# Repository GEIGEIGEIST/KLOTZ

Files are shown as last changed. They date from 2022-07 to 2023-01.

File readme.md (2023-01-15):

<picture>
  <source media="(prefers-color-scheme: dark)" srcset="/docs/images/KLOTZ_font_dark.svg">
  <source media="(prefers-color-scheme: light)" srcset="/docs/images/KLOTZ_font_bright.svg">
  KLOTZ logo font
</picture>

# KLOTZ SPLIT KEYBOARD

KLOTZ is a 34 key column-staggered choc split keyboard running [ZMK](https://zmk.dev/). It supports a low profile encoder, three status LEDs on every side and the SplitKB tenting puck.

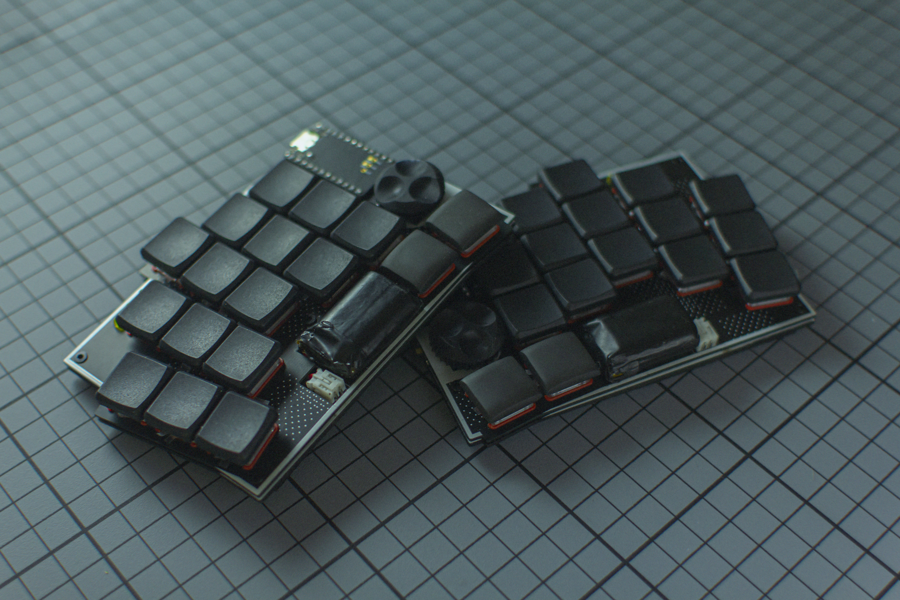
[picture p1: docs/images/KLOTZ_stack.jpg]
KLOTZ stacked


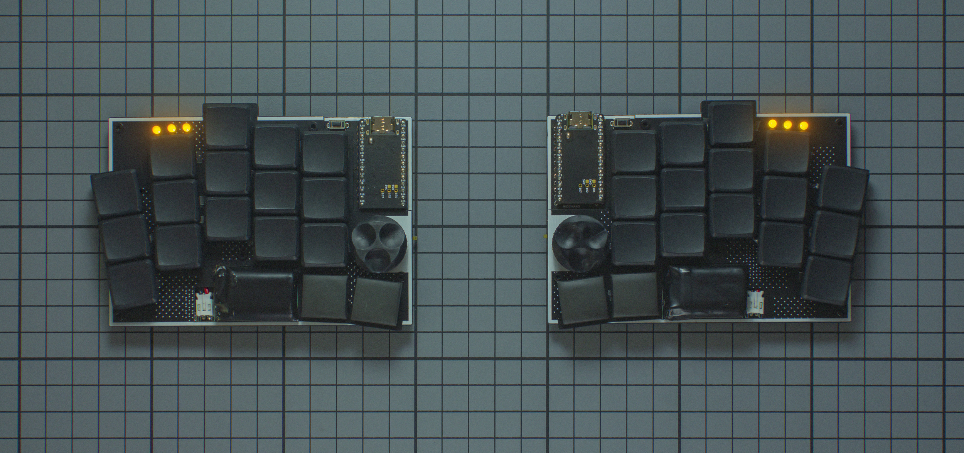
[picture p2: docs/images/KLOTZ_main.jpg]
KLOTZ


## LAYOUT

KLOTZ layout

## PCB

[Here](/PCB/) you can find the KiCad files and Gerbers for the KLOTZ.

## SWITCHPLATE

And [here](/switchplate/) is the switchplate, which you should use, if you plan to use hotswap sockets.

## KNOB

You can use pretty much any knob, which works with EC12 encoder, but [here](/knob/) you can find one, I designed for the KLOTZ.

## BUILD GUIDE

The build guide for the KLOTZ can be found [here](/docs/buildguide.md).

## FIRMWARE

[ZMK config](https://github.com/GEIGEIGEIST/zmk-config-klotz) for the KLOTZ.

## TRAVELCASE

Since a lot of people use the Amazon basics harddrive case (ZH1510147) for the KLOTZ I thought I should put an (affiliate) link in here. 

[US Amazon link](https://www.amazon.com/gp/product/B00F5CKWBA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)

[German Amazon link](https://www.amazon.de/gp/product/B00F5CKWBA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)

 If you build a KLOTZ I would be pretty happy to see some pictures. And if you want to leave me a tip you can do this [here](https://ko-fi.com/geigeigeist) (but please don't feel pressured)

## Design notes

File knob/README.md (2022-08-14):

# KLOTZ KNOB

This is the EC12 encoder knob for the KLOTZ. You should be able to print it in FDM, but for best results consider to print it in SLA.\
I can recommend to get it printed at [JLCPCB](https://jlcpcb.com/)

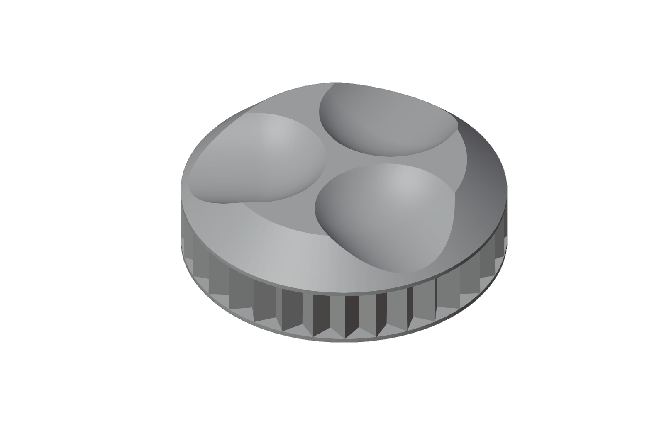
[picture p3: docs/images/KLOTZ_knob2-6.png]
KLOTZ knob


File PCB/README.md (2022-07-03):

# KLOTZ PCB

## MANUFACTURING
If you want to get the PCB made you need to upload the **KLOTZ_0-2_gerbers.zip** file to the website of the manufacture ([JLCPCB](https://jlcpcb.com/) for example).

- upload the ZIP
- sometimes the Gerber preview from JLCPCB can't display the PCB, even when the files are fine. In this case use this dimensions: 120.5 mm* 85.5 mm
- PCB Thickness 1.6mm
- 2 layers
- PCB Qty as much as you like. But be aware, that you need 2 PCBs for one keyboard
- PCB Color Black
- No impedance control
- Surface Finish HASL(with lead) if you want the easiest soldering experience or LeadFree HASL.
- Remove Order Number Yes

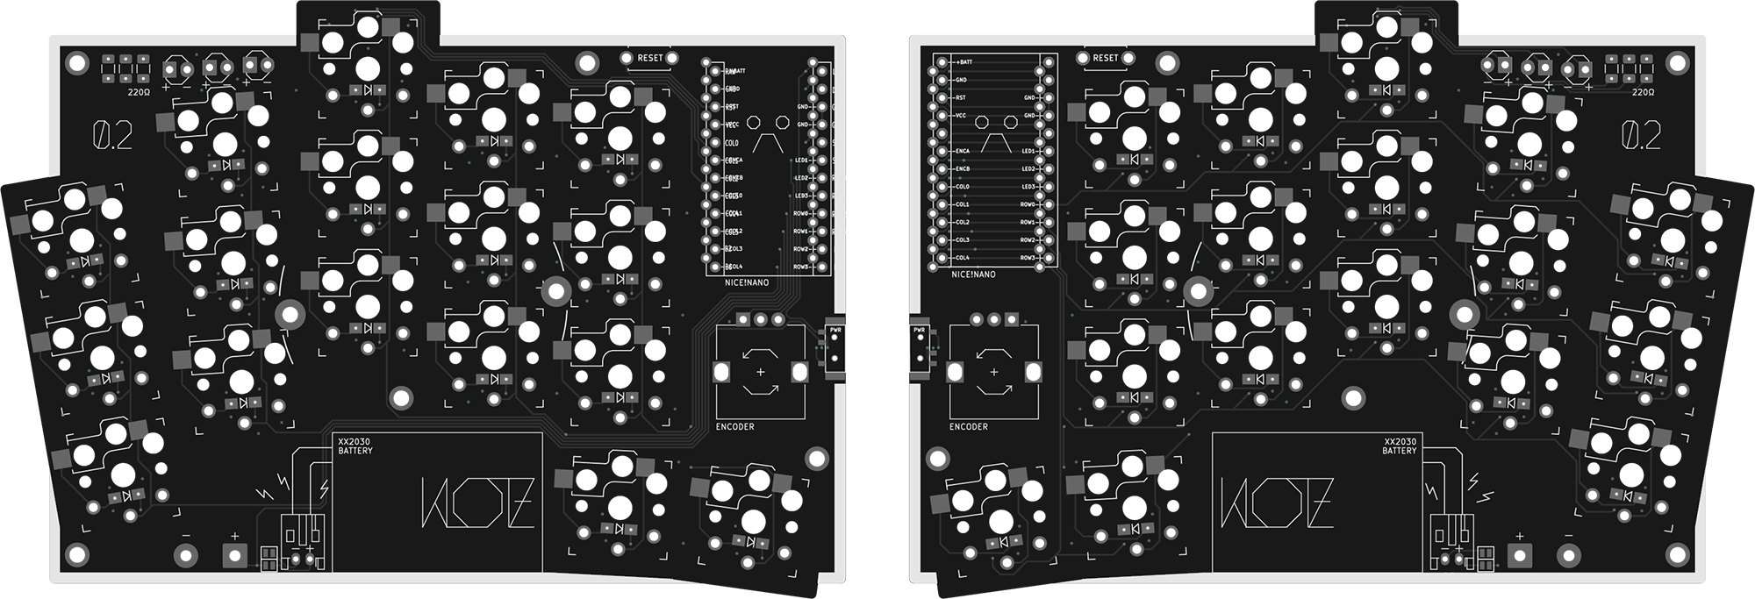
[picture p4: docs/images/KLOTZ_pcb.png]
KLOTZ PCB


## CHECK TRACES OR PINOUT

If you only want to check the traces or see what is connected to which pin you can take a look at these graphics.

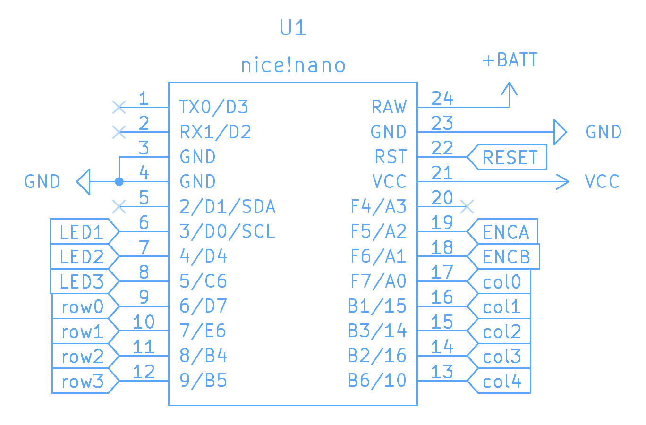
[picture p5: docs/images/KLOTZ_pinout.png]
KLOTZ pinout

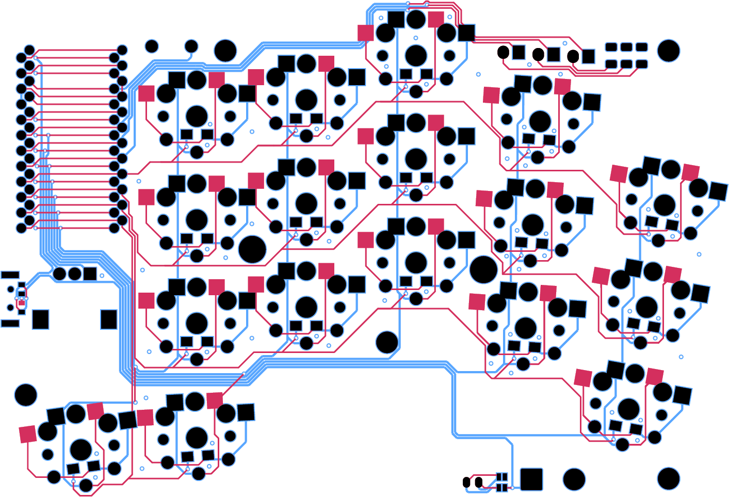
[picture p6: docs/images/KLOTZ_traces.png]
KLOTZ traces


## TAKE A DEEPER LOOK OR MODIFY 

You can download the project if you need to take a deeper look or modify something. You need the Open Source software [KiCad](https://www.kicad.org/) to open it.

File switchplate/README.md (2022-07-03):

# KLOTZ SWITCHPLATE

If you plan to use the KLOTZ with hotswap sockets you should use a switchplate. If you plan on solder in the switches it looks nicer.

## MANUFACTURING
If you want to get the switchplate made you need to upload the **KLOTZ_0-2_plate_gerbers.zip** file to the website of the manufacture ([JLCPCB](https://jlcpcb.com/) for example).

- upload the ZIP
- sometimes the Gerber preview from JLCPCB can't display the PCB, even when the files are fine. In this case use this dimensions: 120.5 mm* 85.5 mm
- PCB Thickness 1.2mm (this is crucial to make Choc switches snap in)
- 2 layers
- PCB Qty as much as you like. But be aware, that you need 2 plates for one keyboard
- PCB Color Black
- No impedance control
- Surface Finish HASL(with lead) or LeadFree HASL
- Remove Order Number Yes
- Flying Probe Test Not Test

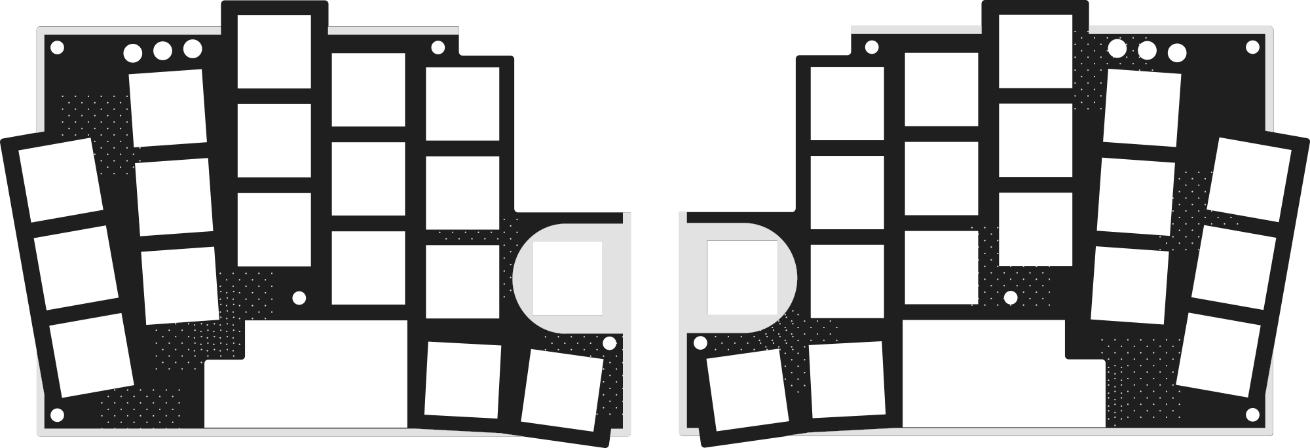
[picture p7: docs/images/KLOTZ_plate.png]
KLOTZ switchplate


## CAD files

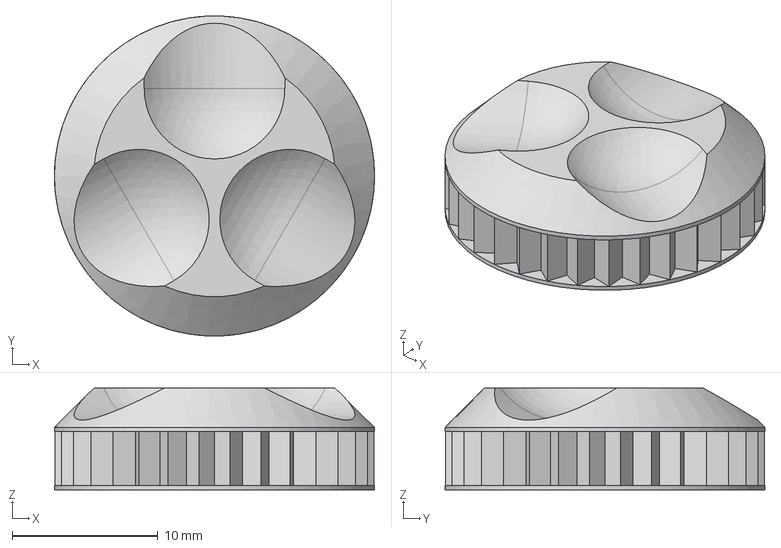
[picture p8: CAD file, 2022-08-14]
knob/GEIST_EC12knob_v02_06.step
22.0 x 22.0 x 7.00 mm

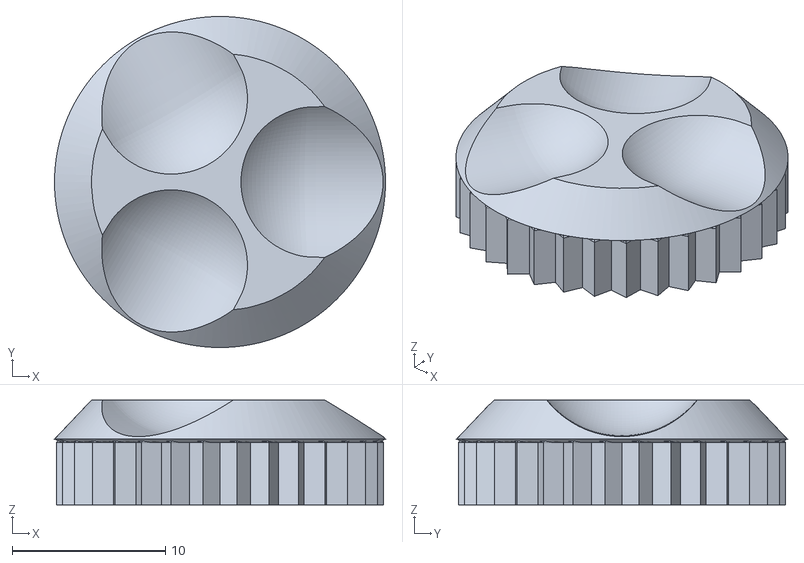
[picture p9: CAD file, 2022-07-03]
knob/KLOTZ_EC12-knob_v02_04.stl
21.6 x 21.6 x 6.86

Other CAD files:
knob/GEIST_EC12knob_v02_06.stl

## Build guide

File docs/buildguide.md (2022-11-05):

# KLOTZ BUILDGUIDE (WIP)

## PART LIST

### REQUIRED PARTS

| Part name | Count | Remarks | 
| :--- | :---: | :--- |
| KLOTZ PCB | 02 | You can find the files for it [here](/PCB/) |
| KLOTZ switchplate | 02 | Which you can find [here](/switchplate/) |
| nice!nano | 02 | Alternatively, you can use another controller with similar pinout and bluetooth capabilities like the Puchi-BLE |
| Choc key switch | 34 | Kailh Choc low profile keyswitches |
| diodes 1N4148W | 34 | These are surface mount diodes in SOD123 package |
| 1u Choc keycaps | 34 | You can use the black or white keycaps from Kailh, but I recommend MBK keycaps |
| reset button | 02 | Through-hole, 2 pin tactile buttons |
| power switch | 02 | MSK12C02 |
| EC12 encoder | 02 | Technically you could also use EC11 encoder, but flat EC12 like the EC12E2440301 will work best |
| encoder knob | 02 | Nearly every encoder knob, which works with the EC12 should work. But if you have acces to a printer you can use [this one](/knob/) |
| USB cable | 01 | For connecting the keyboard with your PC |
| Lipo battery | 02 | You can use a variety of Lipo batteries, but the cutout in the switchplate is meant to be used with a battery which name ends with 2030, like the 902030.

### OPTIONAL PARTS

| Part name | Count | Remarks | 
| :--- | :---: | :--- |
| MCU sockets | 04 | For socketing your MCU. Highly recommended |
| MCU pins | 48 | In combinatin with the MCU sockets |
| JST Jack | 02 | JST PH |
| switch socket | 34 | Switch sockets for Kailh choc switches |
| LEDs | 06 | 3mm through hole LEDs |
| resistors | 06 | R1206 220ohm SMD resistors for the LEDs |
| screws  				 | 10 | 6mm M2 screws |
| bolts | 10 | M2 bolts |
| o-rings | 10 | as optional standoffs. OD4*1.5-150NB |
| [tenting puck](https://splitkb.com/products/tenting-puck)| 02 | SplitKB Tenting Puck |

## INTRODUCTION

Here is an overview of where and on which side each component needs to be soldered (click on the image to see a larger version).

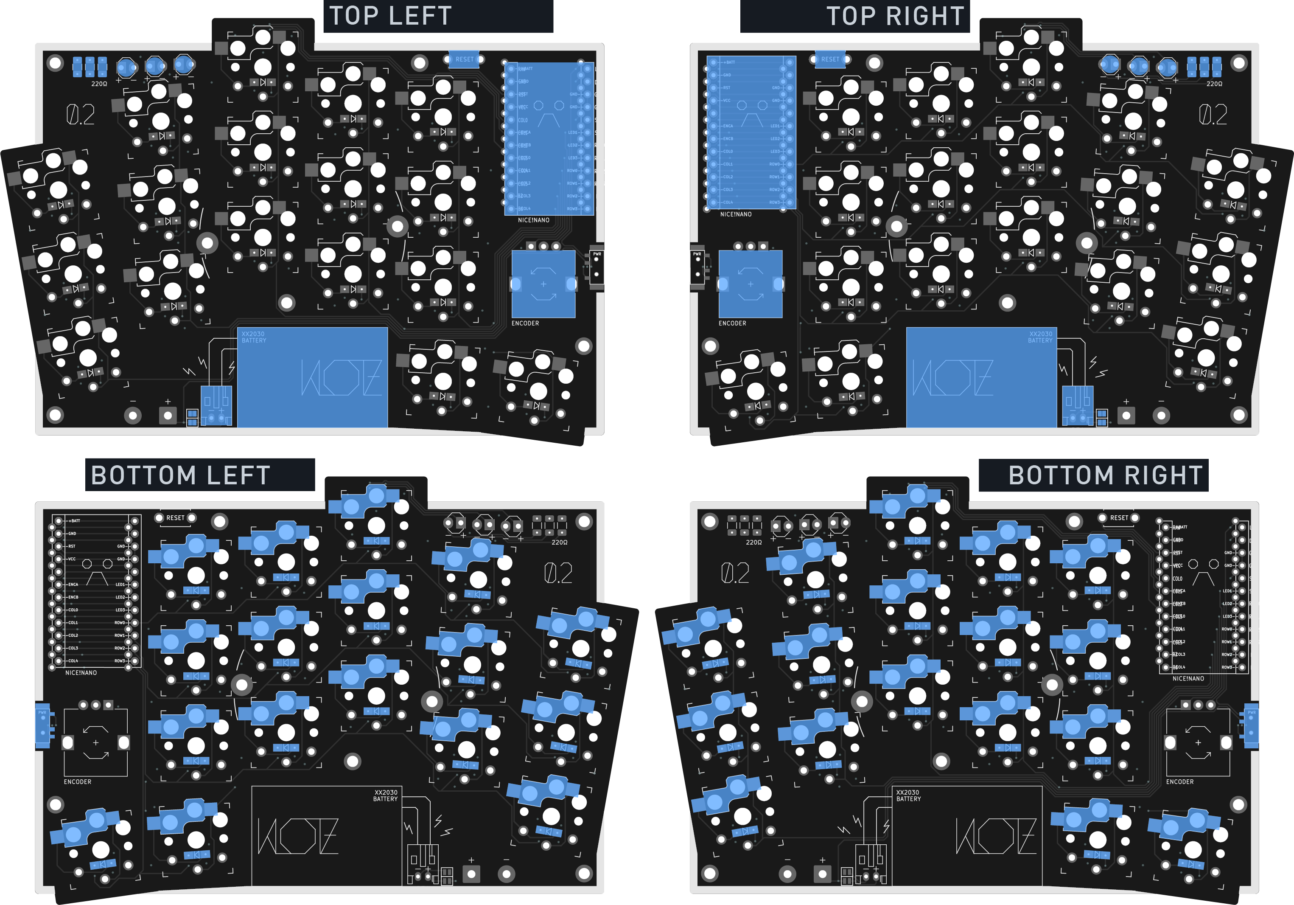
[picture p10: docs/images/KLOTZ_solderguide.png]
KLOTZ solder guide


To see what component needs to sit where you can take a look at the [interactive HTML BOM](https://htmlpreview.github.io/?https://github.com/GEIGEIGEIST/KLOTZ/blob/main/docs/klotz_rev0-2_ibom.html).

> **Warning**
> This interactive HTML BOM does show where each component is located, but please still refer to the solder guide above to see if a component needs to go on the top or bottom of the PCB.

***

## DIODES

The diodes needs to be soldered on the bottomm of the PCB. Pay attention to their orientation:  They have a small line on one side, which should be on the side the arrow on the PCB is facing to.

<p align="center">
<picture>
  <source media="(prefers-color-scheme: dark)" srcset="/docs/images/buildguide/diodes_dark.svg">
  <source media="(prefers-color-scheme: light)" srcset="/docs/images/buildguide/diodes_bright.svg">
  diode orientation
</picture>
</p>

Apply a small amount of solder on one pad.\
Then use tweezers to place the diode on the pads and reheat the solder to secure the diode.
Now you can solder the second pad.

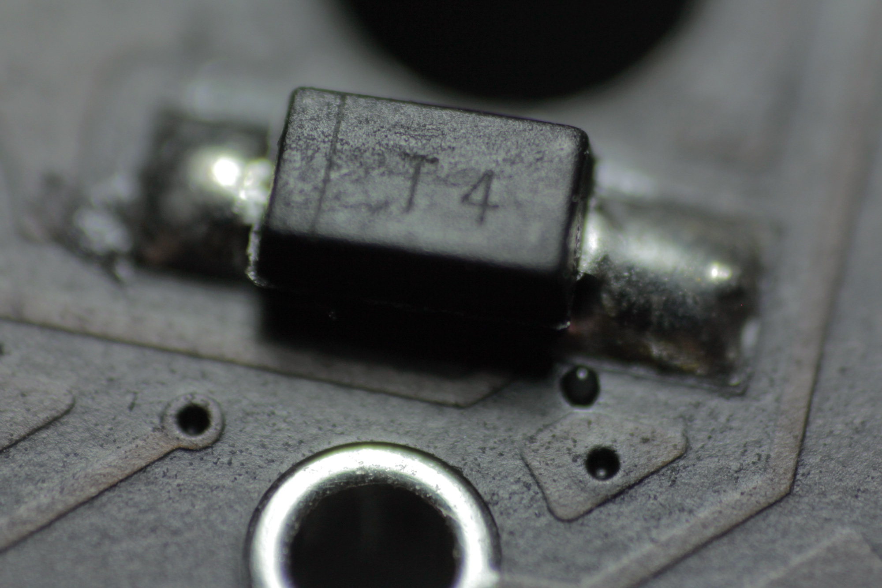
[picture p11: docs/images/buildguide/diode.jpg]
Soldered diode


***

## SWITCH SOCKETS

Here you can apply the same technique as used for the diodes: Apply some solder on one of the pads first.\
Then place the switch socket in the silk screen markings and reheat the solder. Apply some pressure with a pair of tweezers to make sure the socket is fully seated.\
Now solder the second pad.

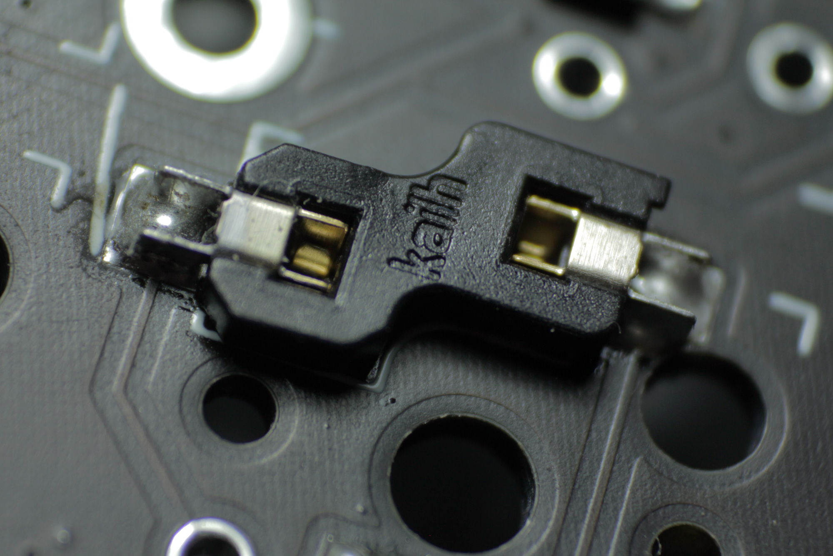
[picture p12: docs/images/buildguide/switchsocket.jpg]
switch socket soldered


***

## POWER SWITCHES

Apply a tiny bit of solder on one of the bigger, outer pads on the bottom of the PCB. The power switch has some tiny knobs on its bottom, which fits into the PCB holes. Hold it in place with tweezers and than reheat the solder on the pad. After this you can solder the other pad and the three pins.

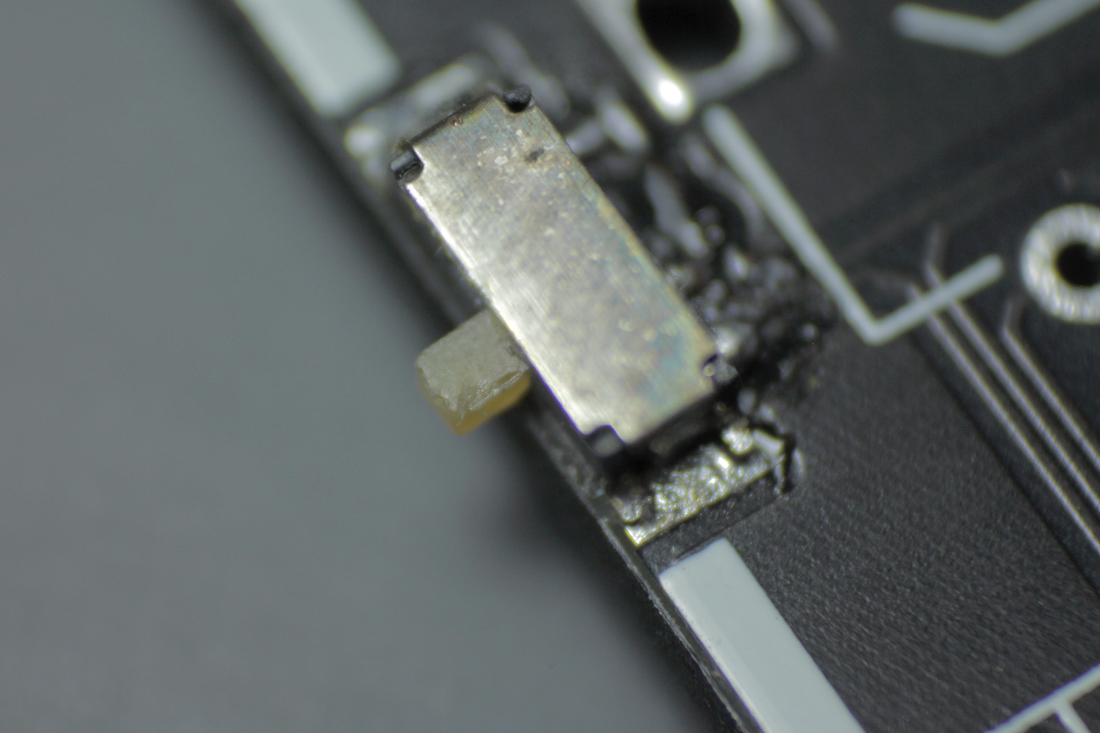
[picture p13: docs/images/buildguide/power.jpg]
power switch


***

## RESET SWITCHES

Put the legs of the reset switch through the holen on the top of the PCB. 
You can secure it with some tape, since you need to solder it from below.

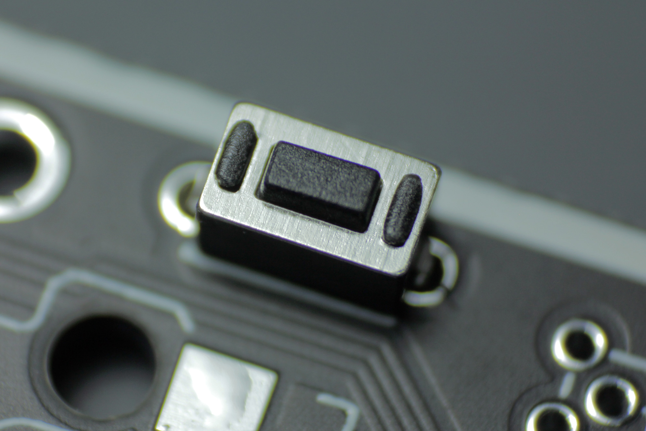
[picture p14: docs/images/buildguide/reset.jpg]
reset switch


***

## MICROCONTROLLER

> **Warning**
> First flash the microcontroller to make sure it works, before soldering it in.

The microcontroller needs to be mounted on the top, with the components facing downwards (to the PCB).\
Feel free to use the included header pins, but it's highly recommended to use MillMax low profile sockets.\
Place the sockets in the marked spots on the bottom side of the PCB.
You can keep them in place by using masking tape.\
Then you can flip the board to solder in the sockets from the bottom.

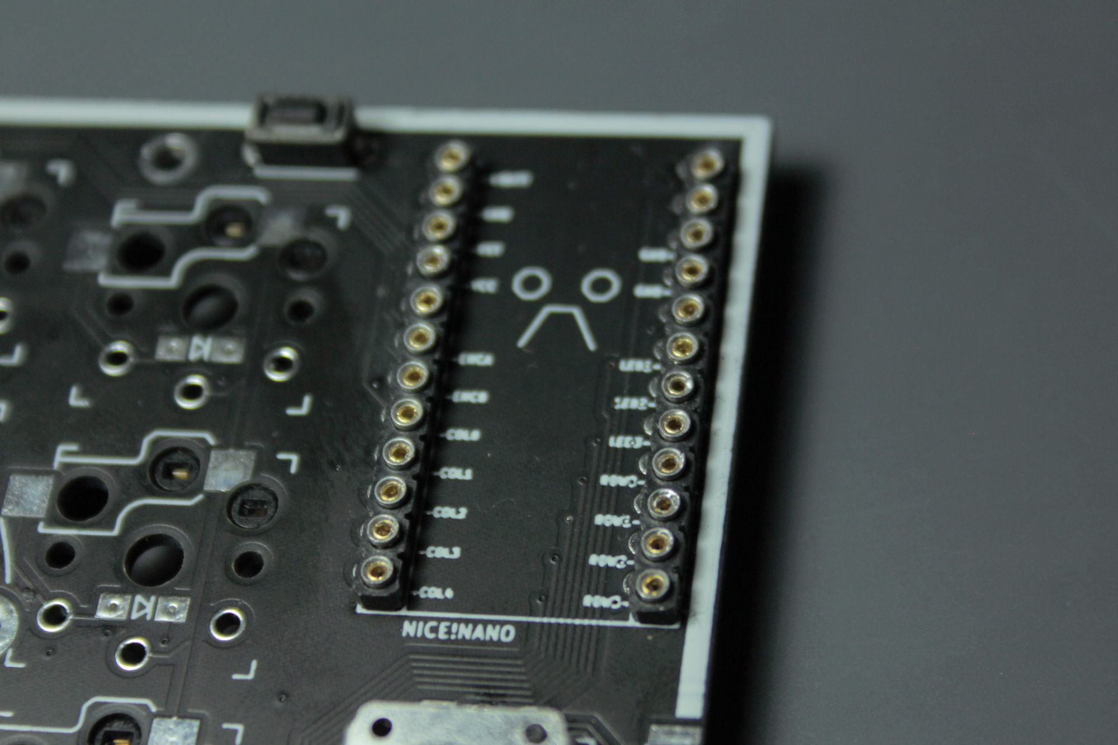
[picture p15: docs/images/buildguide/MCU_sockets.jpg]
MCU sockets


Insert the pins into the sockets.

> **Note**
> Use tweezers to insert them. Don't apply too much force, you will feel them snap in. After that, you can carefully apply some pressure, using a flat object to make sure they're fully seated. 

Now place your microcontroller on the pins (components facing the PCB) and solder it to them.\
You can use flush cutters to trim the header pins.

> **Warning**
> When trimming with flush cutters wear eye protection or hold your hand close above the pins. Otherwise sharp metal pins flying around might hurt you.

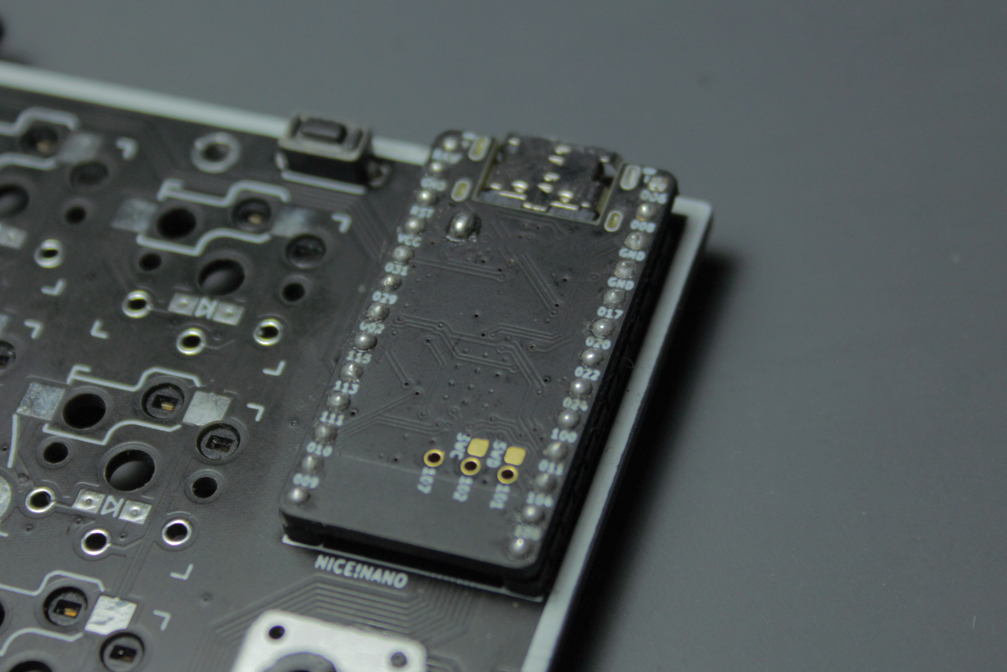
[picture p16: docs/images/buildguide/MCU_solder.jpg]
MCU solder


> **Warning**
> On this image you can see the charge boost jumper of the nice!nano bridged. This increasesd the max charge rate from 100mA to 500mA. Only do this if your battery is at least 500mAh, to avoid explosions. 

***

## LEDS (optional)

Insert the LEDs from above. It helps to use the switchplate to align them, but you need at least two switches to fixate it.
This way you can make sure they won't get in the way later.

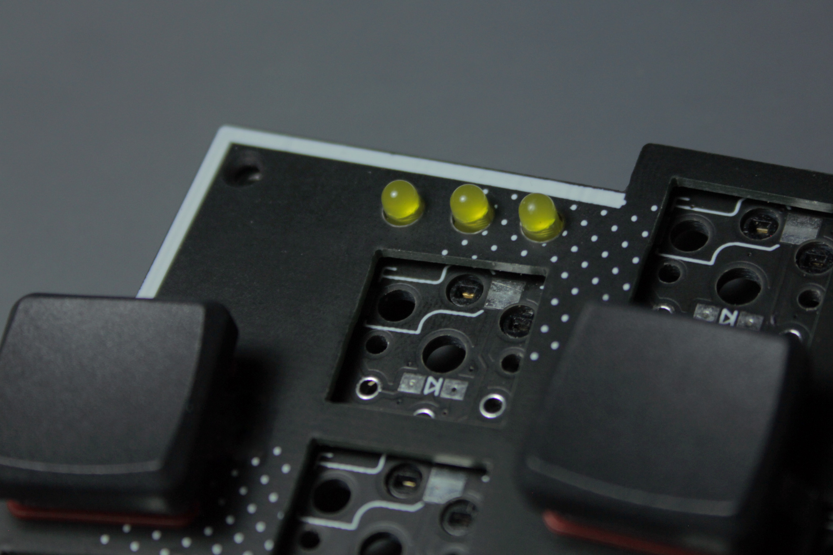
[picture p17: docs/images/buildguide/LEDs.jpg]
LEDs


***

## RESITORS (optional)

Than you should remove the plate and solder the tiny resistors next to the LEDs. As you can see here I still haven't a good technique at hand for doing this.

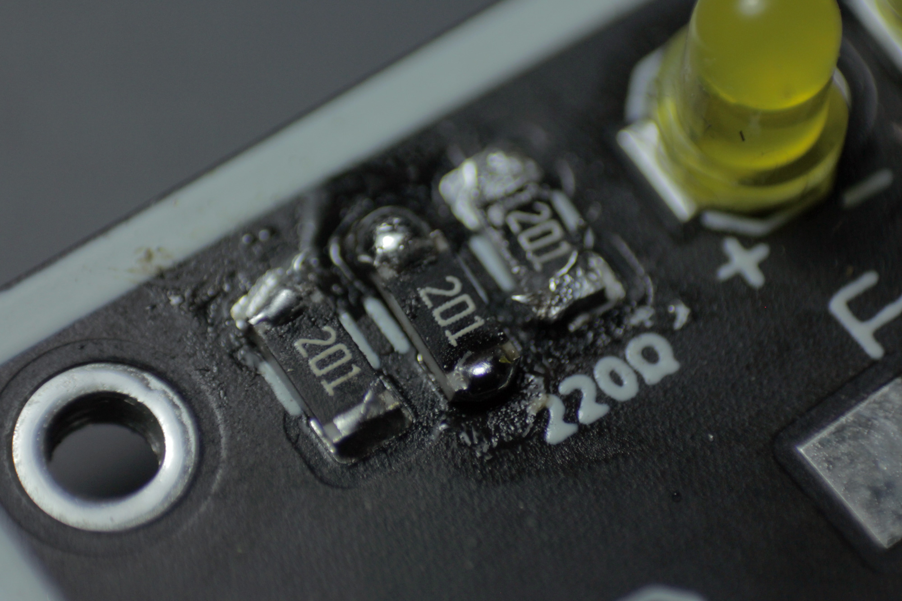
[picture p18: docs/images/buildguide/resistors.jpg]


***

## ENCODERS

> **Note**
> Currently ZMK only supports encoders on the primary side of split keyboards. 

Mount the rotary encoder on the top side of the PCB. It should click into place maybe requiring a firm press. If it's seated correctly solder the pins on the bottom.

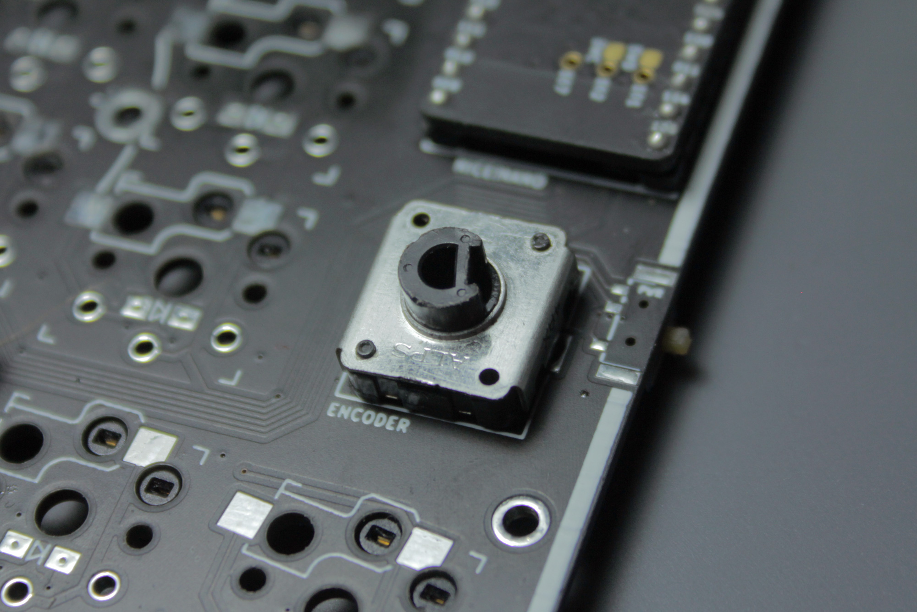
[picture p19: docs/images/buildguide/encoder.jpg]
encoder


***

## JST (optional)

You don't need to solder a JST jack, but it makes it easier to connect and deconnect your batteries, if they already got a JST plug.

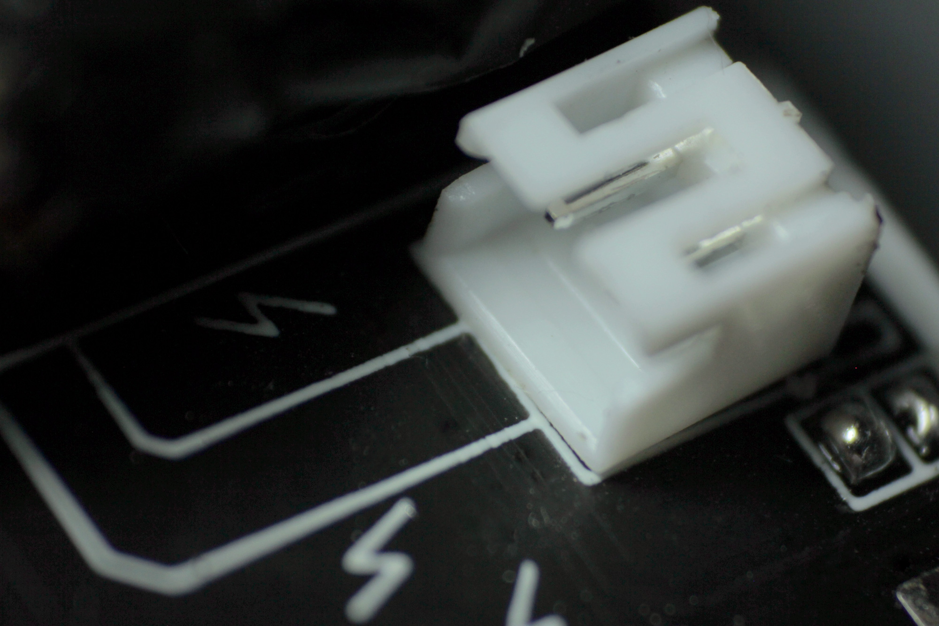
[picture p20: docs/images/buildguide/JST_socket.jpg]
JST jack


If you plan to use a JST jack you also need to bridge the jumpers on the top, next to the JST jack.

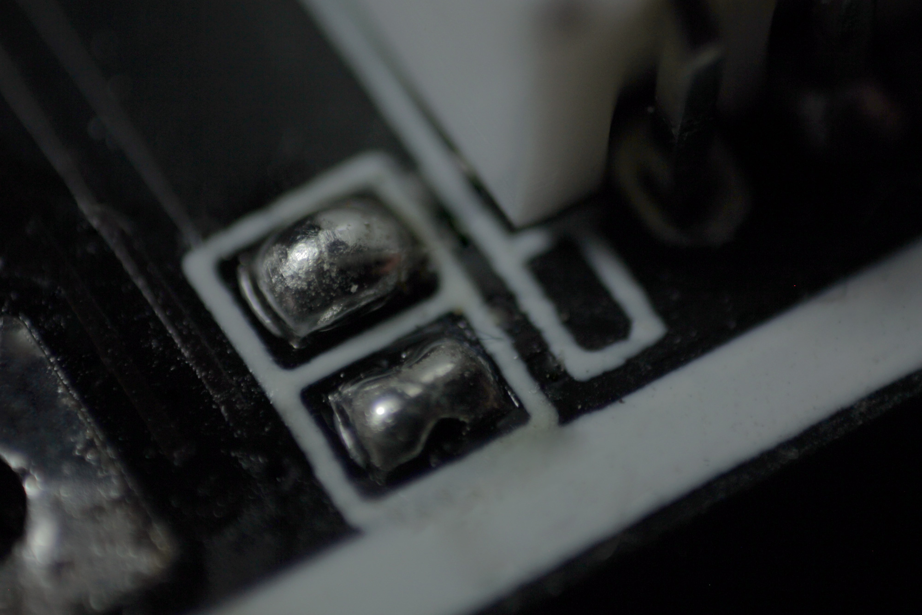
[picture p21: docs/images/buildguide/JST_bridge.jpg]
JST bridge


***

## BATTERY 

If you don't use a JST jack you can solder the wires of your battery to these pads. Red to Plus and Black to Minus.\
In this case you don't need to bridge the jumpers.

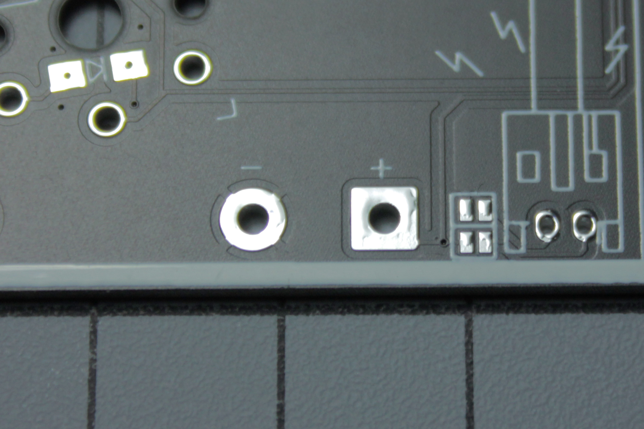
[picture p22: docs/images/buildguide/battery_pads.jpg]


You should use double-sided tape (or even double sided foam tape) to attach the battery to the PCB. You can use the switchplae to align it.

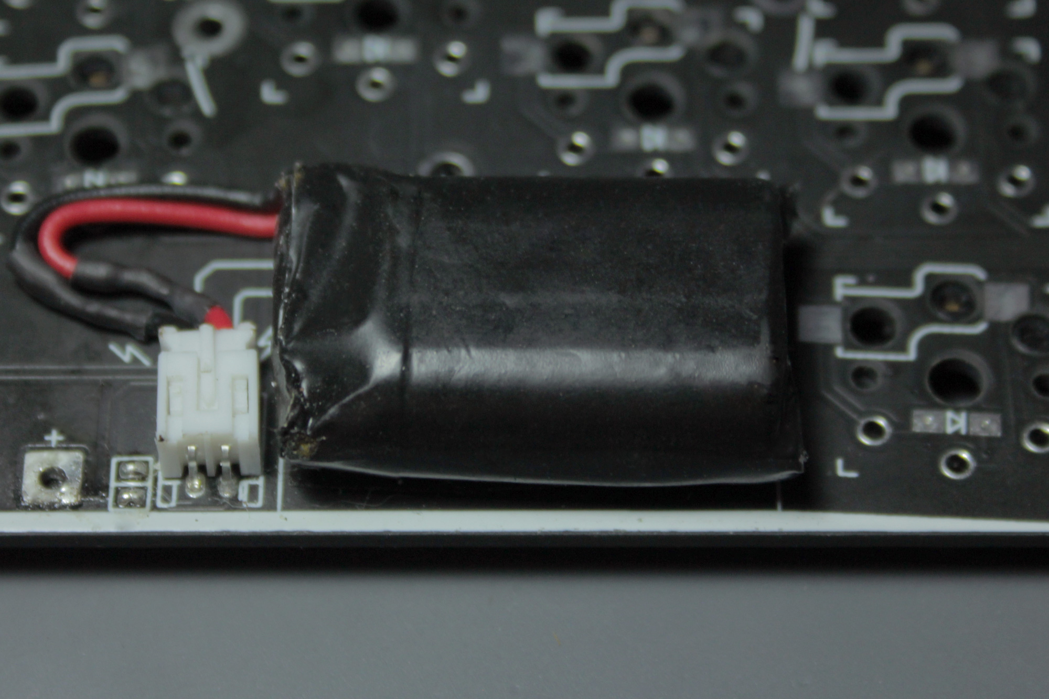
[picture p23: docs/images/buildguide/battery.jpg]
battery


(by the way I plasti-dipped mine, since I dislike the default silver color)

***

## CLEANING

This is how your finished PCB probably will look like. You can use an old toothbrush and some isopropanol to clean it from residues. 

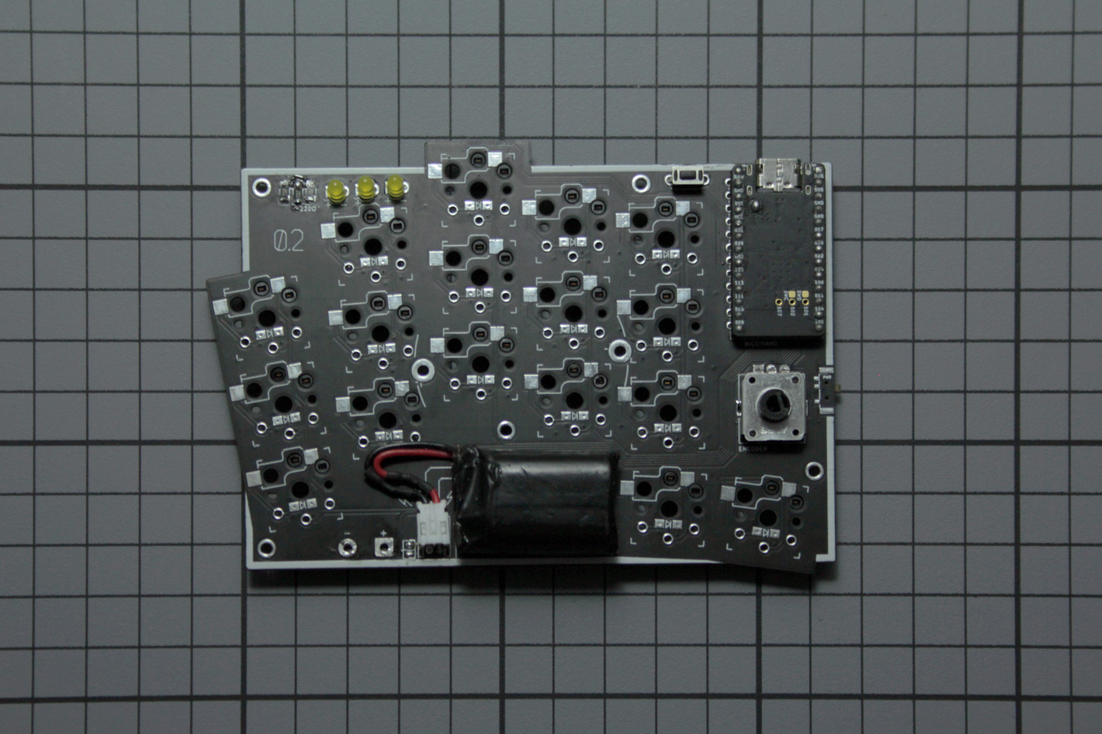
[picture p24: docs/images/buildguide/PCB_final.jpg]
Finished PCB


***

## FIRMWARE

If you have not already flashed the firmware to the microcontroller you should do it now, to make sure everything works, before inserting everyting into the case.\
[Here](https://github.com/GEIGEIGEIST/zmk-config-klotz) you can find the ZMK firmware for the KLOTZ.\
You need to create an own fork of it. In this fork you can edit the keymap to trigger an Github action, which will create your firmware. 

***

## SWITCHPLATE

Since there isn't much space beween switchplate and PCB on choc builds you don't really need screws, but if you use them I recommend O-rings, which are meant to act as spacer between PCB and switchplate. Thick and small ones seem to work best in this case.

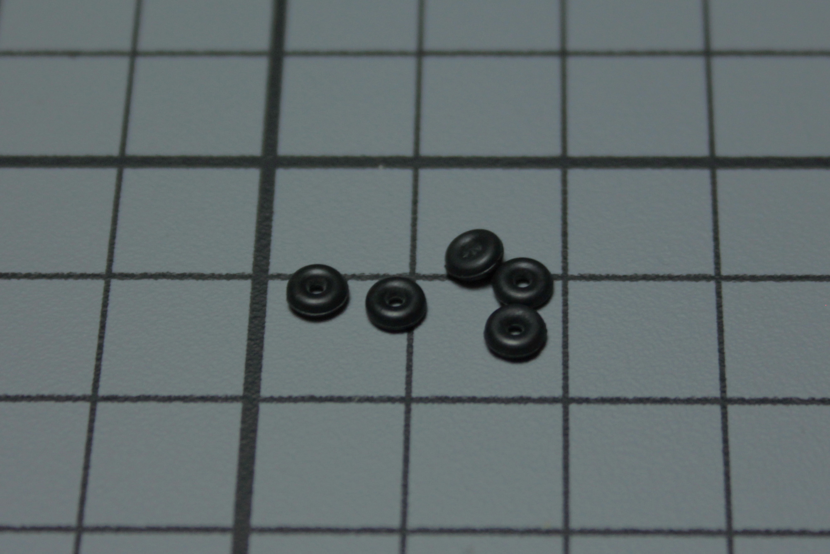
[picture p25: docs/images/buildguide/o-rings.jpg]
O-rings
 

Insert the screws into the holes of the switchplate and use tweezers to secures them with the O-rings.

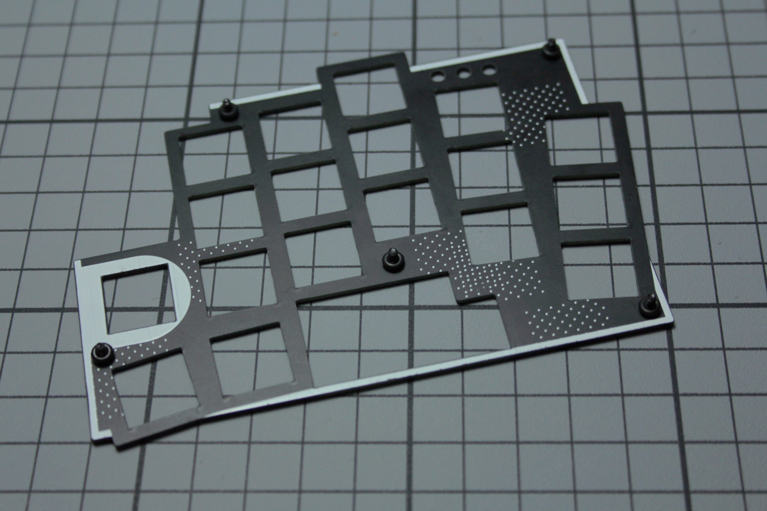
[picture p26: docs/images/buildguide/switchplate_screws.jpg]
switchplate with screws


Attach the plate to the PCB and use some switches to keep it in place, so you can secure it from the bottom with bolts.

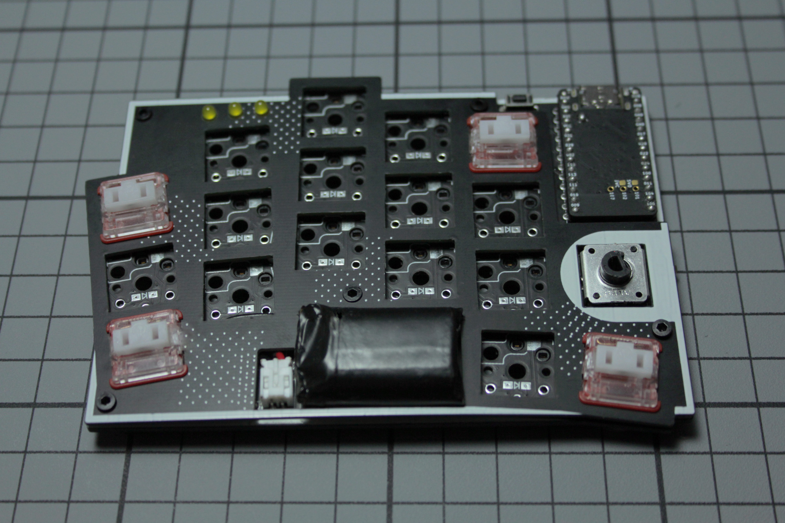
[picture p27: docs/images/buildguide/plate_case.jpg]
plate and PCB


***

## KNOB

This is the 3D printed knob you can find [here](/knob/).

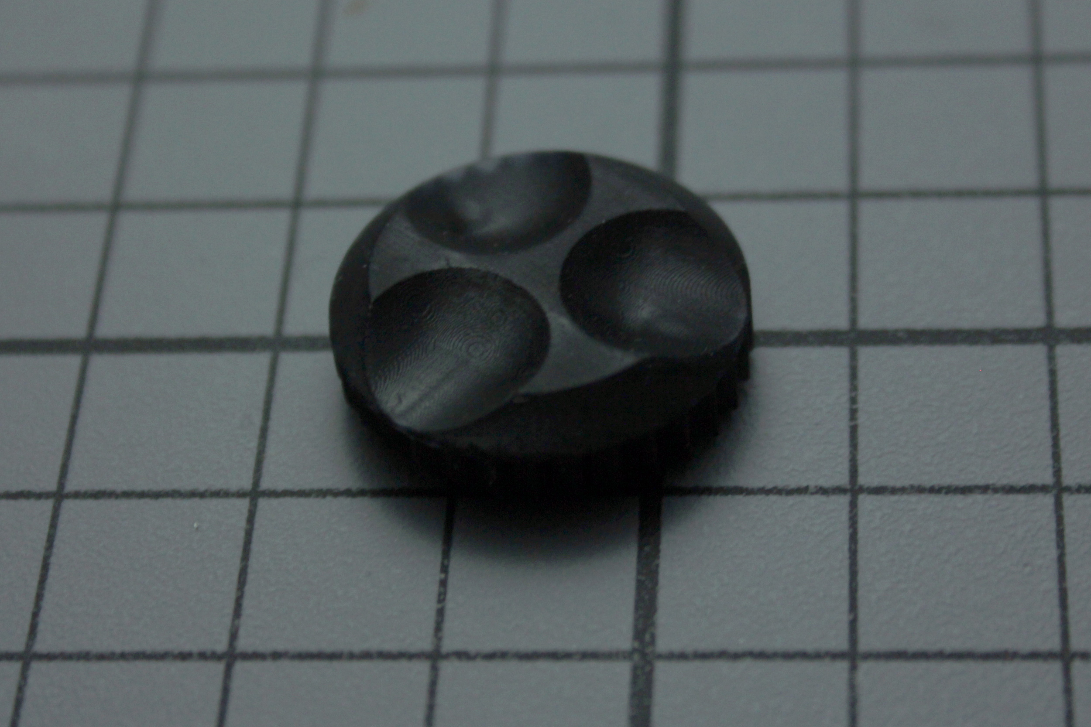
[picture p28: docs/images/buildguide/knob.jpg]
KLOTZ knob


***

## FINAL BUILD

Insert the rest of the switches and put some keycaps on.\
In this picture you see it with Pseudoku CS keycaps on homing keys and thumbs, the other keycaps are MBK blanks.

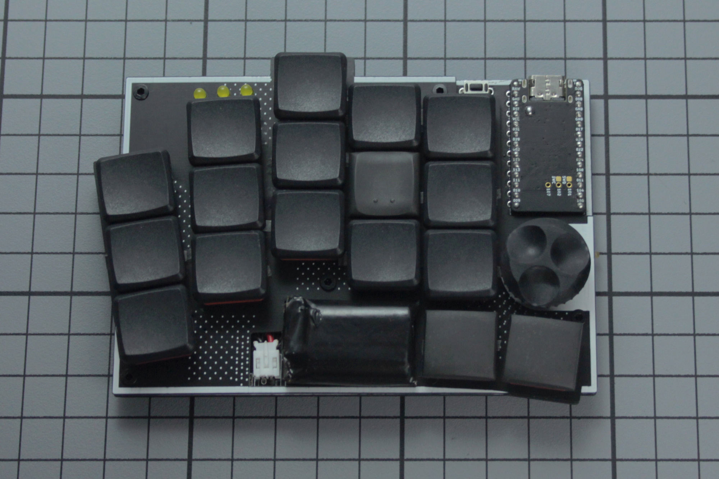
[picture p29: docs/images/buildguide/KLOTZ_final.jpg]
KLOR final


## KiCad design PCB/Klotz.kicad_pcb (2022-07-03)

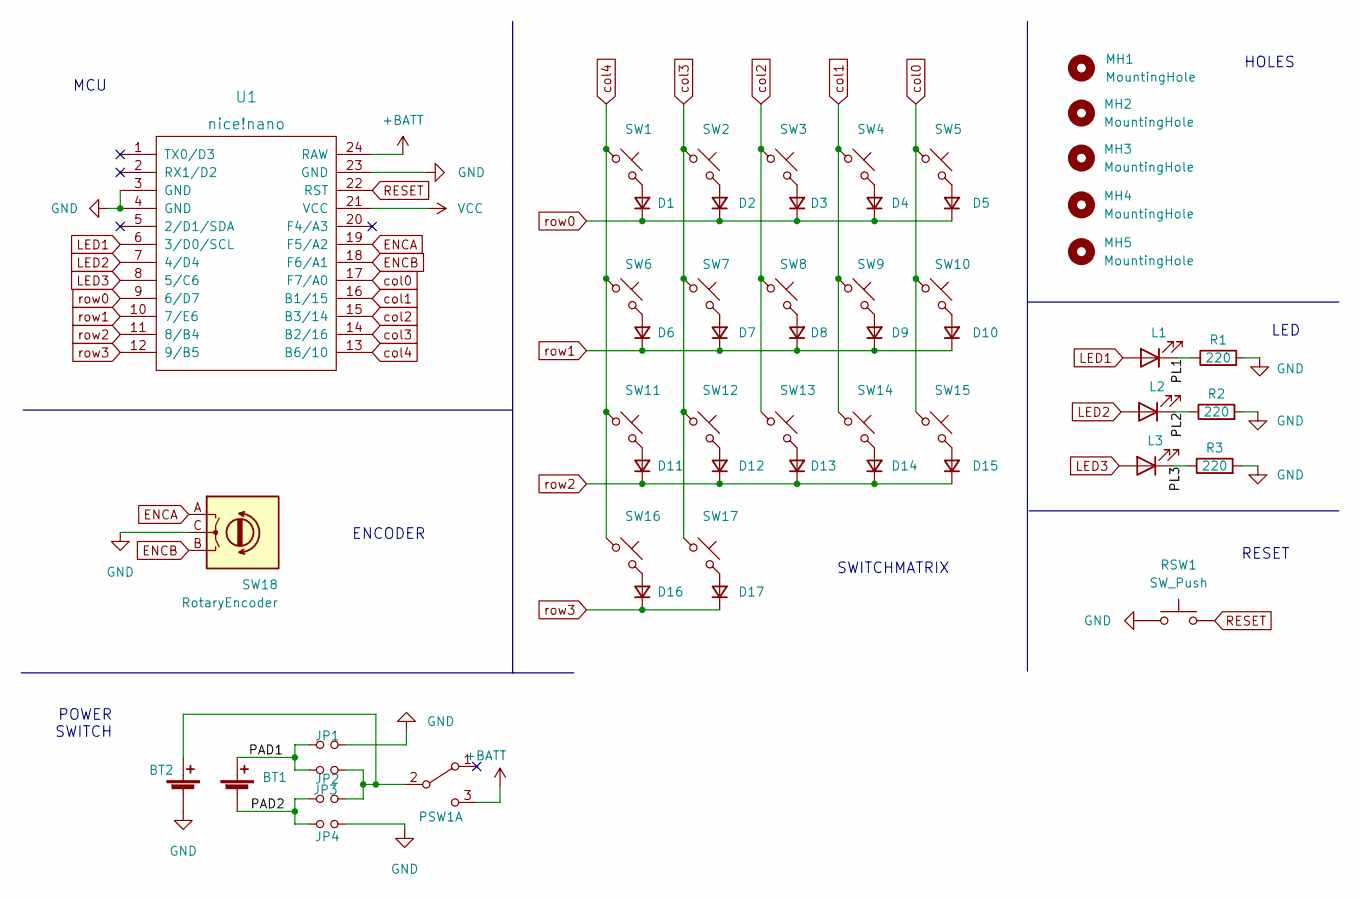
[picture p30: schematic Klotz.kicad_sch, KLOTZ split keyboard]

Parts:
BT1: Battery_Cell; JST_PH_reversible
BT2: Battery_Cell; custombatteryconnector
D1, D2, D3, D4, D5, D6, D7, D8, D9, D10, D11, D12, D13, D14, D15, D16, D17: D_Small; Diode_SOD123
JP1, JP2, JP3, JP4: Device_Jumper_NO_Small; Jumper
L1, L2, L3: LED; LED_3mm_reversible
MH1, MH2, MH3, MH4, MH5: MountingHole; MountingHole_2.2mm_M2_ISO7380_Pad
PSW1: SW_DPDT_x2; MSK12C02_reversible
R1, R2, R3: 220; R_1206_DoubleSided
RSW1: SW_Push
SW1, SW2, SW3, SW4, SW5, SW6, SW7, SW8, SW9, SW10, SW11, SW12, SW13, SW14, SW15, SW16, SW17: MX_SW_HS; Kailh_socket_PG1350_optional_reversible
SW18: RotaryEncoder; RotaryEncoder_Alps_EC12E_Vertical_H20mm
U1: nice!nano; ProMicro_v2

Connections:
+BATT: PSW1.3 (C), U1.24 (RAW)
/PAD1: BT1.1 (+), JP1.1, JP2.1
/PAD2: BT1.2 (-), JP3.1, JP4.1
/PL1: L1.1 (K), R1.1
/PL2: L2.1 (K), R2.1
/PL3: L3.1 (K), R3.1
ENCA: SW18.A, U1.19 (F5/A2)
ENCB: SW18.B, U1.18 (F6/A1)
GND: BT2.2 (-), JP1.2, JP4.2, R1.2, R2.2, R3.2, RSW1.1, SW18.C, U1.3 (GND), U1.4 (GND), U1.23 (GND)
LED1: L1.2 (A), U1.6 (3/D0/SCL)
LED2: L2.2 (A), U1.7 (4/D4)
LED3: L3.2 (A), U1.8 (5/C6)
unnamed: BT2.1 (+), JP2.2, JP3.2, PSW1.2 (B)
unnamed: D1.2 (A), SW1.2
unnamed: D2.2 (A), SW2.2
unnamed: D3.2 (A), SW3.2
unnamed: D4.2 (A), SW4.2
unnamed: D5.2 (A), SW5.2
unnamed: D6.2 (A), SW6.2
unnamed: D7.2 (A), SW7.2
unnamed: D8.2 (A), SW8.2
unnamed: D9.2 (A), SW9.2
unnamed: D10.2 (A), SW10.2
unnamed: D11.2 (A), SW11.2
unnamed: D12.2 (A), SW12.2
unnamed: D13.2 (A), SW13.2
unnamed: D14.2 (A), SW14.2
unnamed: D15.2 (A), SW15.2
unnamed: D16.2 (A), SW16.2
unnamed: D17.2 (A), SW17.2
RESET: RSW1.2, U1.22 (RST)
VCC: U1.21 (VCC)
col0: SW5.1, SW10.1, SW15.1, U1.17 (F7/A0)
col1: SW4.1, SW9.1, SW14.1, U1.16 (B1/15)
col2: SW3.1, SW8.1, SW13.1, U1.15 (B3/14)
col3: SW2.1, SW7.1, SW12.1, SW17.1, U1.14 (B2/16)
col4: SW1.1, SW6.1, SW11.1, SW16.1, U1.13 (B6/10)
row0: D1.1 (K), D2.1 (K), D3.1 (K), D4.1 (K), D5.1 (K), U1.9 (6/D7)
row1: D6.1 (K), D7.1 (K), D8.1 (K), D9.1 (K), D10.1 (K), U1.10 (7/E6)
row2: D11.1 (K), D12.1 (K), D13.1 (K), D14.1 (K), D15.1 (K), U1.11 (8/B4)
row3: D16.1 (K), D17.1 (K), U1.12 (9/B5)

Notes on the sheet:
SWITCHMATRIX
POWER SWITCH
HOLES
LED
MCU
RESET
ENCODER

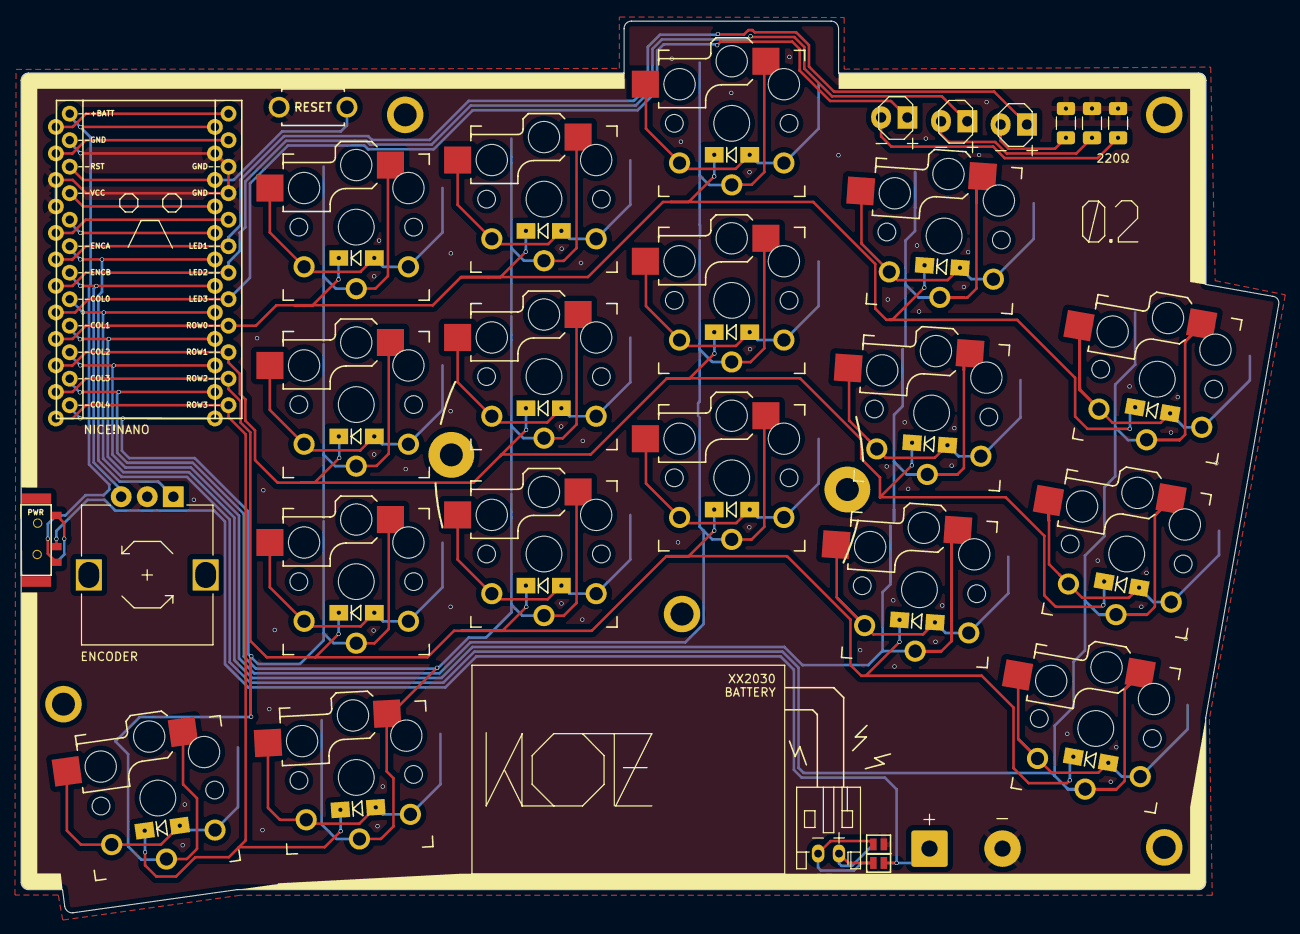
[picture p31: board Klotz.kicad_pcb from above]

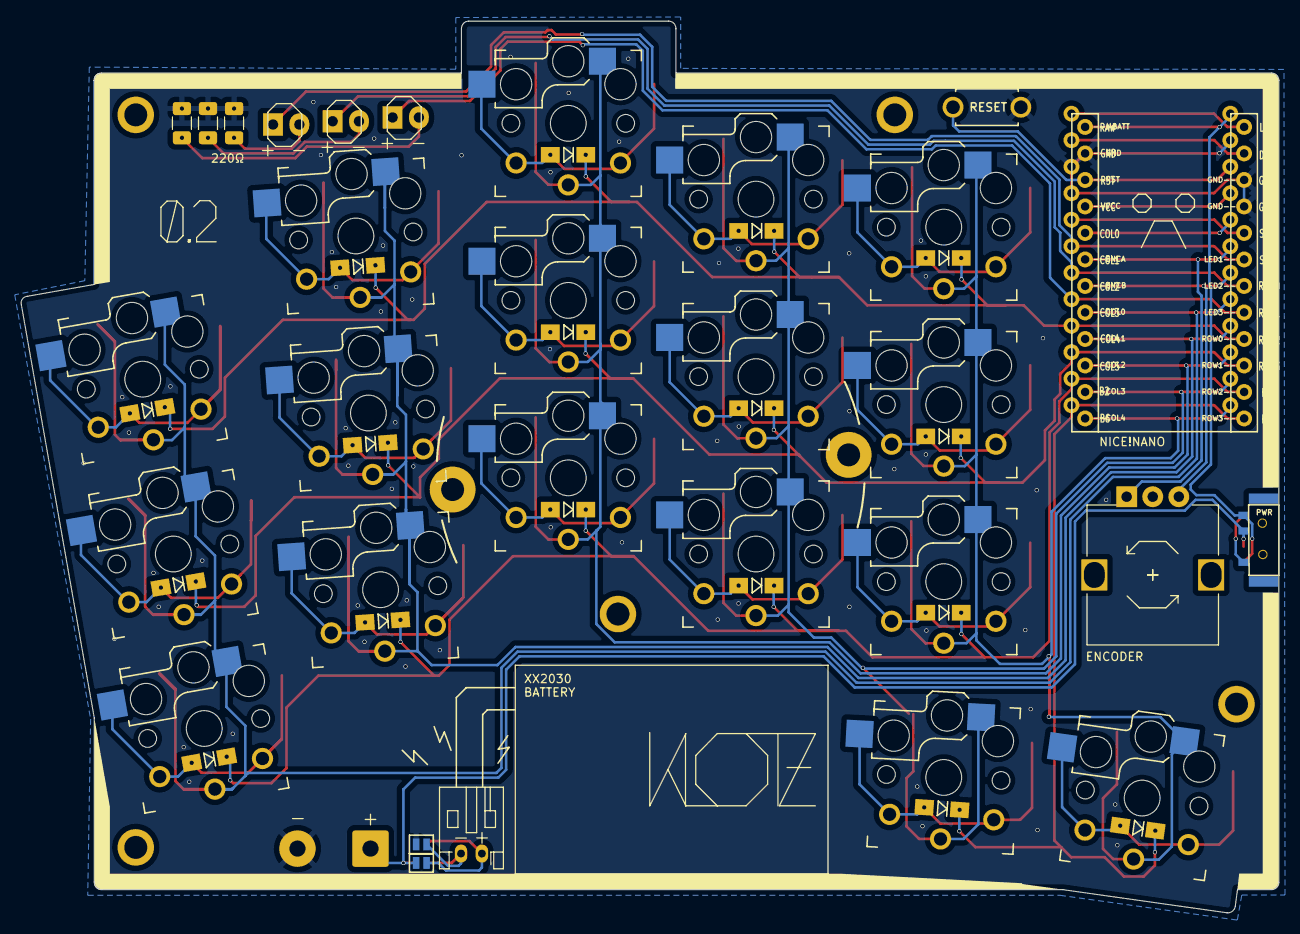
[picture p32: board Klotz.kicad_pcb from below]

Board: 2 copper layers, 120.5 x 85.5 mm, 55 parts (3 on the bottom side), 40 nets.

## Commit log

2022-07-02 upload PCB
    [Klotz-B_Cu.gbl, Klotz-B_Mask.gbs, Klotz-B_Paste.gbp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]
2022-07-02 add plate files
    [Klotz_02_Plate-B_Cu.gbl, Klotz_02_Plate-B_Mask.gbs, Klotz_02_Plate-B_Paste.gbp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]
2022-07-03 add knob
    [KLOTZ_EC12-knob_v02_04.stl]
2022-07-03 update KiCad files
    [Klotz-B_Cu.gbl, Klotz-B_Mask.gbs, Klotz-B_Paste.gbp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]
2022-07-03 update PCB readme
2022-07-03 update bom
2022-08-14 update knob
    [GEIST_EC12knob_v02_06.step, GEIST_EC12knob_v02_06.stl]
